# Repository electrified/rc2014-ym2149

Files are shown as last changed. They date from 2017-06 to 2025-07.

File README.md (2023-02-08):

# YM2149F/AY-3-8190 Sound card for the RC2014 computer - Revision 6.1

The `head` of this repository contains the latest version - currently **Rev 6.1**. Please check the version of your board, and select the appropriate tag from the right to get the documentation for your board. e.g [go here for the **Rev 5** (most common) docs](https://github.com/electrified/rc2014-ym2149/tree/4b8af5396633bc87178b81087cec0f71b8307908)

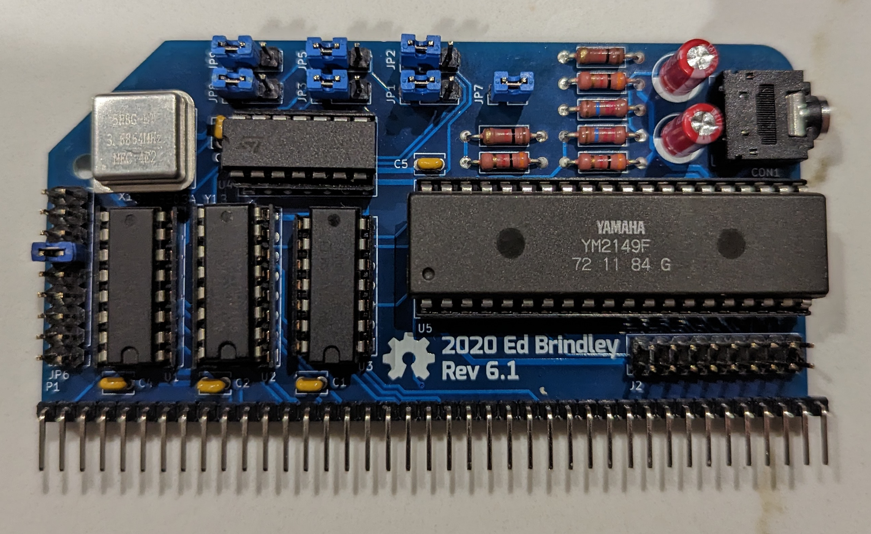
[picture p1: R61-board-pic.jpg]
Picture of the board


Video demonstration: https://www.youtube.com/watch?v=-iLwi9FagFE

## The board
This is a YM2149F/AY-3-8910 sound card for the RC2014 Z80 8-bit computer. It adds the ability to play music on your RC2014!

## What can you use this for?
* Playing music for MSX or ColecoVision Super Game Module compatible software (you may also want a TMS9918A board)
* Playing music ripped from spectrum games
* Playing Spectrum Protracker 2/3 and tunes in MYM format
* Adding music to your own games
* Making music from BASIC or ASM!

## Features

* Stereo Line out, with golden ratio mixer.
* Header for the 2 8-bit I/O ports. These could be used for reading from joysticks, additional serial ports, LED indicators etc.
* Both YM2149F and AY-3-8910 ICs may be used
* Supported in RomWBW
* Possible to jumper to the same IO port as the ZX Spectrum AY
* Known to work on the standard RC2014 setup, as well as on Steve Cousin's SC126 and SC130
* Divides the RC2014 clock by 2 or 4 using flip flops to bring it under the 2Mhz max clock speed of the AY.
* Supports enabling the YM2149F's internal clock divider. This means that bus speeds up to 16Mhz could be supported without overclocking the chip. (AY does not have this feature)
* [George Beckett](https://twitter.com/markgbeckett/) has done some great work getting the board working on the [Minstrel 4th Jupiter Ace compatible computer](https://www.thefuturewas8bit.com/minstrel4th.html). See [his repository here](https://github.com/markgbeckett/jupiter_ace/tree/master/rc2014_sound_card) for information. 

## History
The Yamaha YM2149F and General Instrument AY-3-8910 are popular sound chips that were used in a wide variety of computers and arcade machines in the 1980s and 1990s. The most notable of those being the ZX Spectrum 128, Atari ST and MSX computers.

## Construction Steps

0. If you have bought one of Spencer's kits, obtain a YM2149 chip from your local friendly eBay seller :)
1. Verify the components supplied in the kit match up with [bill of materials](https://github.com/electrified/rc2014-ym2149/blob/master/README.md#bill-of-materials)
2. Solder the components to the board, matching the components in the [BOM](https://github.com/electrified/rc2014-ym2149/blob/master/README.md#bill-of-materials) to the component references printed on the PCB, starting with the lowest height ones first e.g. bypass capacitors and resistors, then moving on to IC sockets, pin headers and do the electrolytic capacitors and output jack last.
3. Insert the ICs in their sockets. The component reference marking on the PCB (e.g. U1) is nearest to pin 1 for all ICs
4. If you have a Z80 based system, configure the jumpers on the board so it looks like the picture in the README. This will ensure it is at the right IO address.
5. Insert board into backplane/SBC
6. Boot into RomWBW ensure you have the "tune.com" application (it's not included in the ROM drive but should be on the disk images)
7. Find some music to play. There are some example files in https://github.com/wwarthen/RomWBW/tree/dev/Source/Apps/Tune/Tunes that you could transfer to the system.
8. Use tune.com to play the music file. If you download the RomWBW*-Package.zip corresponding to whatever version of RomWBW you are using the from the releases page here https://github.com/wwarthen/RomWBW/releases, the tune.com executable will be in the `Binary/Apps` directory.

## Bill Of Materials

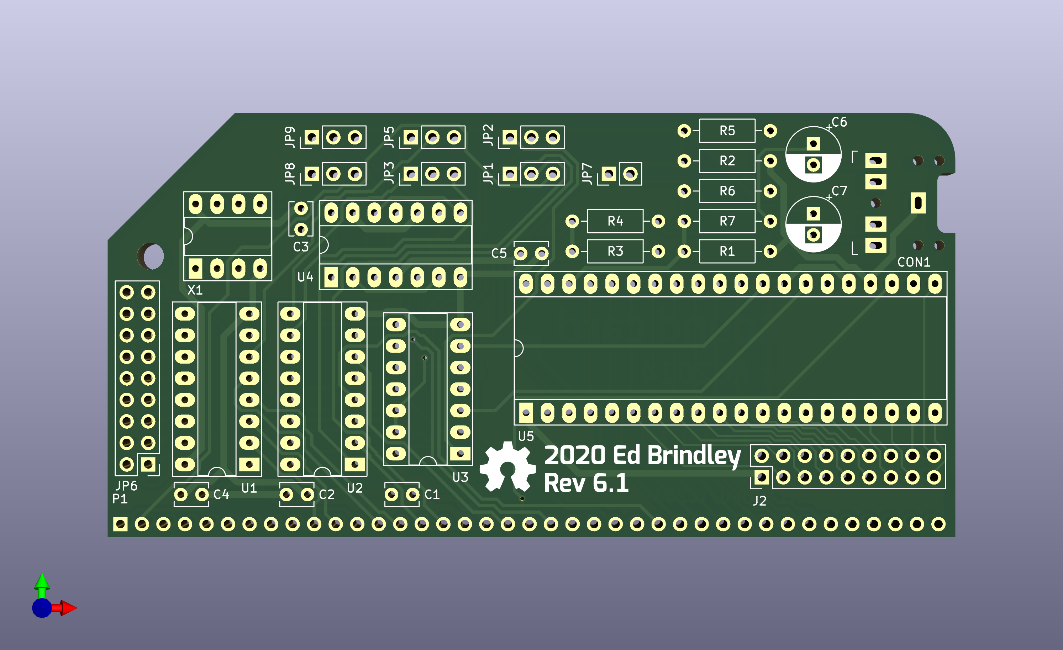
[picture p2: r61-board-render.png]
Picture of the board


Qty|Schematic Reference|Description
---|-------------------|-----------
2|U1 U2| 16 pin DIP socket 2.54 mm pin pitch, 7.62 mm wide
1|U5|	40 pin DIP socket, 2.54mm pin pitch, 15.24mm wide
1|U5|	Yamaha YM2149F or General Instrument AY-3-8910
1|U4|	74HCT74
2|U3 U4| 14 pin DIP socket 2.54 mm pin pitch, 7.62 mm wide
1|U3|	74HCT00
2|U1 U2| 74HCT138
2|R6 R7| 1k6 ohm 1/4 watt metal film resistor
2|R4 R5| 1k ohm 1/4 watt metal film resistor
3|R1 R2 R3|	3k ohm 1/4 watt metal film resistor
1|P1|	40 pin right angled 2.54mm header
1|CON1|	3 or 5 pin 3.5mm PCB mount jack socket (e.g. SJ1-3525N - mouser part 710-860020472001)
2|C6 C7| 4.7uF electrolytic capacitor
5|C1 C2 C3 C4 C5|	0.1uF ceramic capacitor 2.54 mm pin pitch
7|JP1-5 JP8-JP9| 3 x 1 straight pin header 2.54 mm pin pitch
1|JP7| 2 x 1 straight pin header 2.54 mm pin pitch
1|JP6| 9 x 2 straight pin header 2.54 mm pin pitch
1|J2| 9 x 2 straight pin header 2.54 mm pin pitch
1|X1| Half size Oscillator socket (or DIP-8 socket with middle pins removed)
5|Various|Jumpers

The majority of the components are widely available, however both the AY-3-8910 and YM2194F are unfortunately not in production any more, but reclaimed chips are available fairly plentifully on eBay from suppliers in China. I would suggest using a standard 40 pin DIL socket for the AY as they are more accommodating to bent/soldered pins than a turned pin ones.

## Addressing

The board contains a set of jumpers to select the address at which the sound chip will respond to commands.  The jumpers settings are described in detail below.

"Normal" or MSX addressing mode is recommended.

### Normal/MSX/ColecoVision addressing
MSX mode uses standard 8-bit port addressing. This board allows the base address to be any value from 00-F0 (MSX uses A0 and ColecoVision SGM uses 50 for the PSG's base address). Different ports in the lower nybble are used for reading and writing the address and data registers.  Writing to port `X0h` selects the PSG register. Writing to port `X1h` writes the selected PSG register value and reading port `X2h` reads the selected PSG register value.

i.e. for MSX:
Configure base address: A0h
Register write address: A0h
Data write address: A1h
Data read address: A2h

and ColecoVision
Configure base address: 50h
Register write address: 50h
Data write address: 51h
Data read address: 52h

### ZX Spectrum addressing
ZX Spectrum mode uses an uncommon 16-bit I/O addressing scheme for the PSG. This is possible since the Z80 puts the value of the B register on the upper 8 bits of the address bus when performing an `IN r, (C)` or `OUT (C), r` instruction.  Setting `A15` to `1` and `A1` to `0` enables the PSG and `A14` distinguishes between PSG address and data registers. To select a PSG register, set `BC` to `FFFDh` and use `OUT (C), r` to select the address in r. To write a value to the selected PSG register set `BC` to `BFFDh` and use `OUT (C), r` to write the value in r. To read the selected PSG register value, set `BC` to `FFFDh` and use `IN r, (C)`. Note that r must be A, D, E, H, or L since B and C are required for addressing.  Also note that `OUT (n), A` and `IN A, (n)` instructions won't work since they put the value of A on the upper 8 bits of the address bus.

### Compatibility with Rev 5
REV6 no longer supports the `D0/D8` addresses used by default in REV5 and earlier.  REV6 introduced MSX-compatible addressing and supporting addresses used by REV5 and earlier would have required additional chips. This seems like a fair tradeoff since existing software that uses the original default addresses for this board is minimal compared to software that uses the MSX or Spectrum addressing schemes.

Note: Pin 1 on each jumper is identified by having square pad.

### JP1-JP3
Select between MSX and ZX Spectrum decoding. All 3 jumpers should all be set to either MSX or ZX Spectrum mode. For Spectrum mode, JP6 must also be set in position 17-18.  Mixing modes on different jumpers will result in nonsensical address decoding.

pins                 |description
---------------------|--------------
1-2 (Left Position)  | Normal/MSX/ColecoVision
2-3 (Right Position) | ZX Spectrum

### JP5
Selects the upper or lower half of the address range selected by JP6.

pins                 | description
---------------------|------------
1-2 (Left position)  | Upper (odd) half
2-3 (Right position) | Lower (even) half

### JP6
Selects the base address for MSX addressing mode. For Spectrum addressing, the rightmost position (17-18) must be used.  MSX addressing can use any base address from 00-F0, where JP6 selects the 3 most significant bits.  JP5 is used to set `A4`, thus selecting the lower or upper half of the range chosen by JP5.

pins|with JP5 on 1&2
----|------------
1-2 (Bottom most position) | 0x00
3-4 | 0x20
5-6 | 0x40
7-8 | 0x60
9-10 | 0x80
11-12 | 0xA0 (MSX Compatible)
13-14 | 0xC0
15-16 | 0xE0
17-18 (Top most position) | Spectrum Mode

pins|with JP5 on 2&3
----|------------
1-2 (Bottom most position) | 0x10
3-4 | 0x30
5-6 | 0x50 (ColecoVision SGM compatible)
7-8 | 0x70
9-10 | 0x90
11-12 | 0xB0
13-14 | 0xD0
15-16 | 0xF0
17-18 (Top most position) | Spectrum Mode

### JP7

YM2149 only, internally halve clock if jumpered

### JP8

Use bus clock or onboard oscillator

pins|description
----|------------
1-2 | Oscillator
2-3 | Bus clock

### JP9
Clock divisor. Divides the bus or oscillator 

pins|description
----|------------
1-2 | Divide by 2
2-3 | Divide by 4 - Default

## Outputs

CON1 - 3.5mm audio out

J2 - 2 8 bit I/O ports

## How to use from BASIC

See the BASIC programs in ```player/test```. ```descend.bas``` plays some descending tones, ```io_in.bas``` demonstrates reading from the IO port, and ```io_out.bas``` demonstrates writing to an IO port.

## How to use from RomWBW

Wayne has incorporated a player called "Tune" into RomWBW that will play PT2, PT3 and MYM files. See here for the source: https://github.com/wwarthen/RomWBW/tree/master/Source/Apps/Tune. It should be present within RomWBW disk images.

Alternatively start the Microsoft BASIC interpreter mbasic, and refer to the above BASIC examples.

## MSX Configuration

#A0 (write) 	Register write port
#A1 (write) 	Value write port
#A2 (read) 	Value read port

## Sources for music to play

ZXArt is my favourite site: https://zxart.ee/eng/music/mainpage/

http://zxtunes.com/ is another massive collection.

http://ftp.kameli.net/pub/mym/ has a collection of MYM files

This tool compresses YMs to MYMs, which makes a lot of music available: http://osdk.org/index.php?page=documentation&subpage=ym2mym although your mileage may vary, I found some YMs weren't convertible.

This is a large archive of YM tunes to try with the above tool: ftp://ftp.modland.com/pub/modules/YM/

The CPC Power site has a lot of Amstrad YMs: https://www.cpc-power.com/index.php?page=database

There are some PT2s, PT3s and YMs on Sergei Bulba's site: http://bulba.untergrund.net/music_e.htm (although a lot of tunes in other formats)

## Credits
* Some ideas and the golden ratio output mixing were taken from the Melodik 2 design here: http://hw.speccy.cz/melodik2.html
* MSX decoding, many thanks to J.B. Langston

## License

Copyright Ed Brindley 2017-2022.

This source describes Open Hardware and is licensed under the CERN-OHL-P v2
You may redistribute and modify this documentation and make products using it under the terms of the CERN-OHL-P v2 (https:/cern.ch/cern-ohl). This documentation is distributed WITHOUT ANY EXPRESS OR IMPLIED WARRANTY, INCLUDING OF MERCHANTABILITY, SATISFACTORY QUALITY AND FITNESS FOR A PARTICULAR PURPOSE. Please see the CERN-OHL-P v2 for applicable conditions

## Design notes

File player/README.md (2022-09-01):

# Assembling within a Docker container

## Prerequisites
* Docker
* This repo checked out

## Building the docker image
To build the docker container containing the tools, change into this directory in the git checkout then
```
docker build -t z80-build .
```

You should see some output similar to the following (there will be a lot more when built for the first time with no cache)

```
Sending build context to Docker daemon  586.2kB
Step 1/4 : FROM debian:unstable-slim
 ---> 36663c2c334f
Step 2/4 : RUN apt-get -y update && apt-get -y install build-essential git bison flex libxml2-dev subversion zlib1g-dev m4 ragel re2c dos2unix texinfo texi2html gdb curl perl cpanminus ccache libboost-all-dev libmodern-perl-perl libyaml-perl liblocal-lib-perl libcapture-tiny-perl libpath-tiny-perl libtext-table-perl libdata-hexdump-perl libregexp-common-perl libclone-perl libfile-slurp-perl && cpanm --local-lib=~/perl5 App::Prove CPU::Z80::Assembler Data::Dump Data::HexDump File::Path List::Uniq Modern::Perl Object::Tiny::RW Regexp::Common Test::Harness Text::Diff Text::Table YAML::Tiny && eval $(perl -I ~/perl5/lib/perl5/ -Mlocal::lib) && git clone --recurse-submodules --branch v1.20.1 https://github.com/z00m128/sjasmplus.git && git clone --recurse-submodules https://github.com/z88dk/z88dk.git && cd sjasmplus && make && cd ../z88dk && export BUILD_SDCC=1 && export BUILD_SDCC_HTTP=1 && chmod 777 build.sh && ./build.sh
 ---> Using cache
 ---> 2d4bfb98bbca
Step 3/4 : ENV PATH "/z88dk/bin:/sjasmplus:$PATH"     ZCCCFG="/z88dk/lib/config/"
 ---> Using cache
 ---> 472186f6ac08
Step 4/4 : WORKDIR /src
 ---> Using cache
 ---> a4e7ad1df2e2
Successfully built a4e7ad1df2e2
Successfully tagged z80-build:latest
```

## Running the assembler
To assemble PTxPlay with tune and generate an intel hex file, run the following commands

First run this to assemble
```
docker run -v ${PWD}:/src/ -it z80-build sjasmplus PTxPlay.asm
```

You should see output similar to
```
SjASMPlus Z80 Cross-Assembler v1.20.1 (https://github.com/z00m128/sjasmplus)
Pass 1 complete (0 errors)
Pass 2 complete (0 errors)
PTxPlay.asm(292): warning: value 0x1F0 is truncated to 8bit value: 0xF0
PTxPlay.asm(352): warning: value 0xC774 is truncated to 8bit value: 0x74
PTxPlay.asm(399): warning: value 0xC780 is truncated to 8bit value: 0x80
PTxPlay.asm(672): warning: value 0x1A3E5 is truncated to 16bit value: 0xA3E5
PTxPlay.asm(994): warning: value 0xC949 is truncated to 8bit value: 0x49
PTxPlay.asm(1058): warning: value 0xC849 is truncated to 8bit value: 0x49
PTxPlay.asm(1412): warning: value 0xDD8 is truncated to 8bit value: 0xD8
PTxPlay.asm(1424): warning: value 0xCDA is truncated to 8bit value: 0xDA
PTxPlay.asm(1437): warning: value 0xE08 is truncated to 8bit value: 0x08
PTxPlay.asm(1449): warning: value 0xFC0 is truncated to 8bit value: 0xC0
include data: name=tunes/MmcM_-_Recollection_(2015).pt3 (7963 bytes) Offset=0  Len=7963
Pass 3 complete
Errors: 0, warnings: 10, compiled: 1513 lines, work time: 0.004 seconds
```

Then convert the binary file to intel hex with the following
```
docker run -v ${PWD}:/src/ -it z80-build z88dk-appmake +rom -b PTxPlay.out --org 49152 --ihex
```

You should now have a PTxPlay.ihx in the current directory.

## Changing the song being played
Search for `MDLADDR EQU $` in PTxPlay.asm and change the referenced song

## Changing the port
Search for `IF RC` and adjust the output code ports

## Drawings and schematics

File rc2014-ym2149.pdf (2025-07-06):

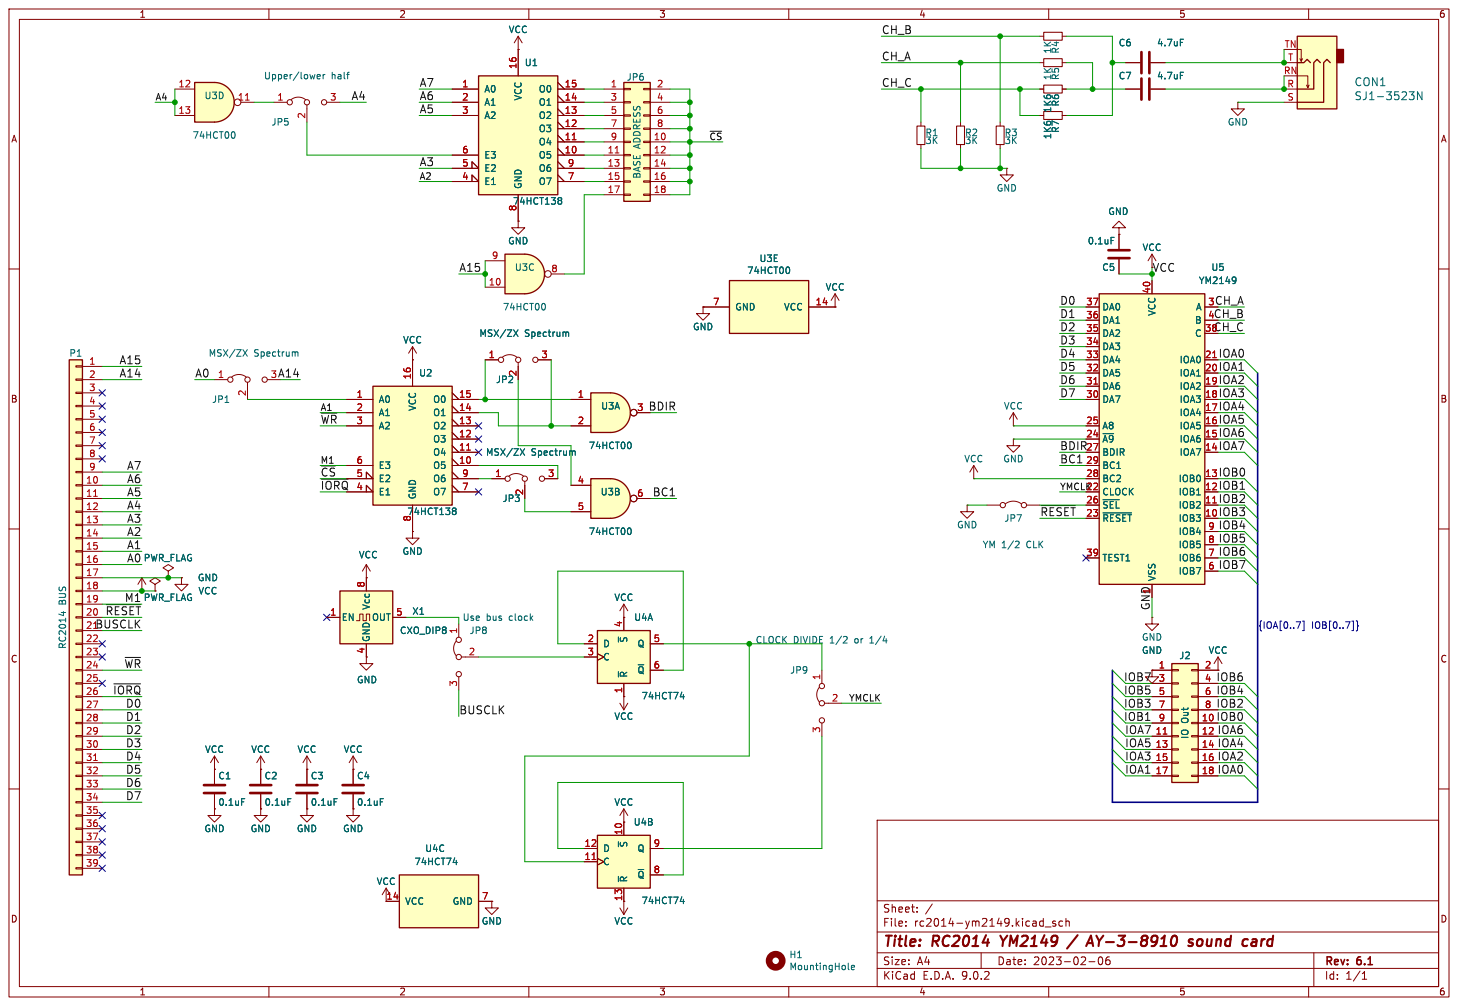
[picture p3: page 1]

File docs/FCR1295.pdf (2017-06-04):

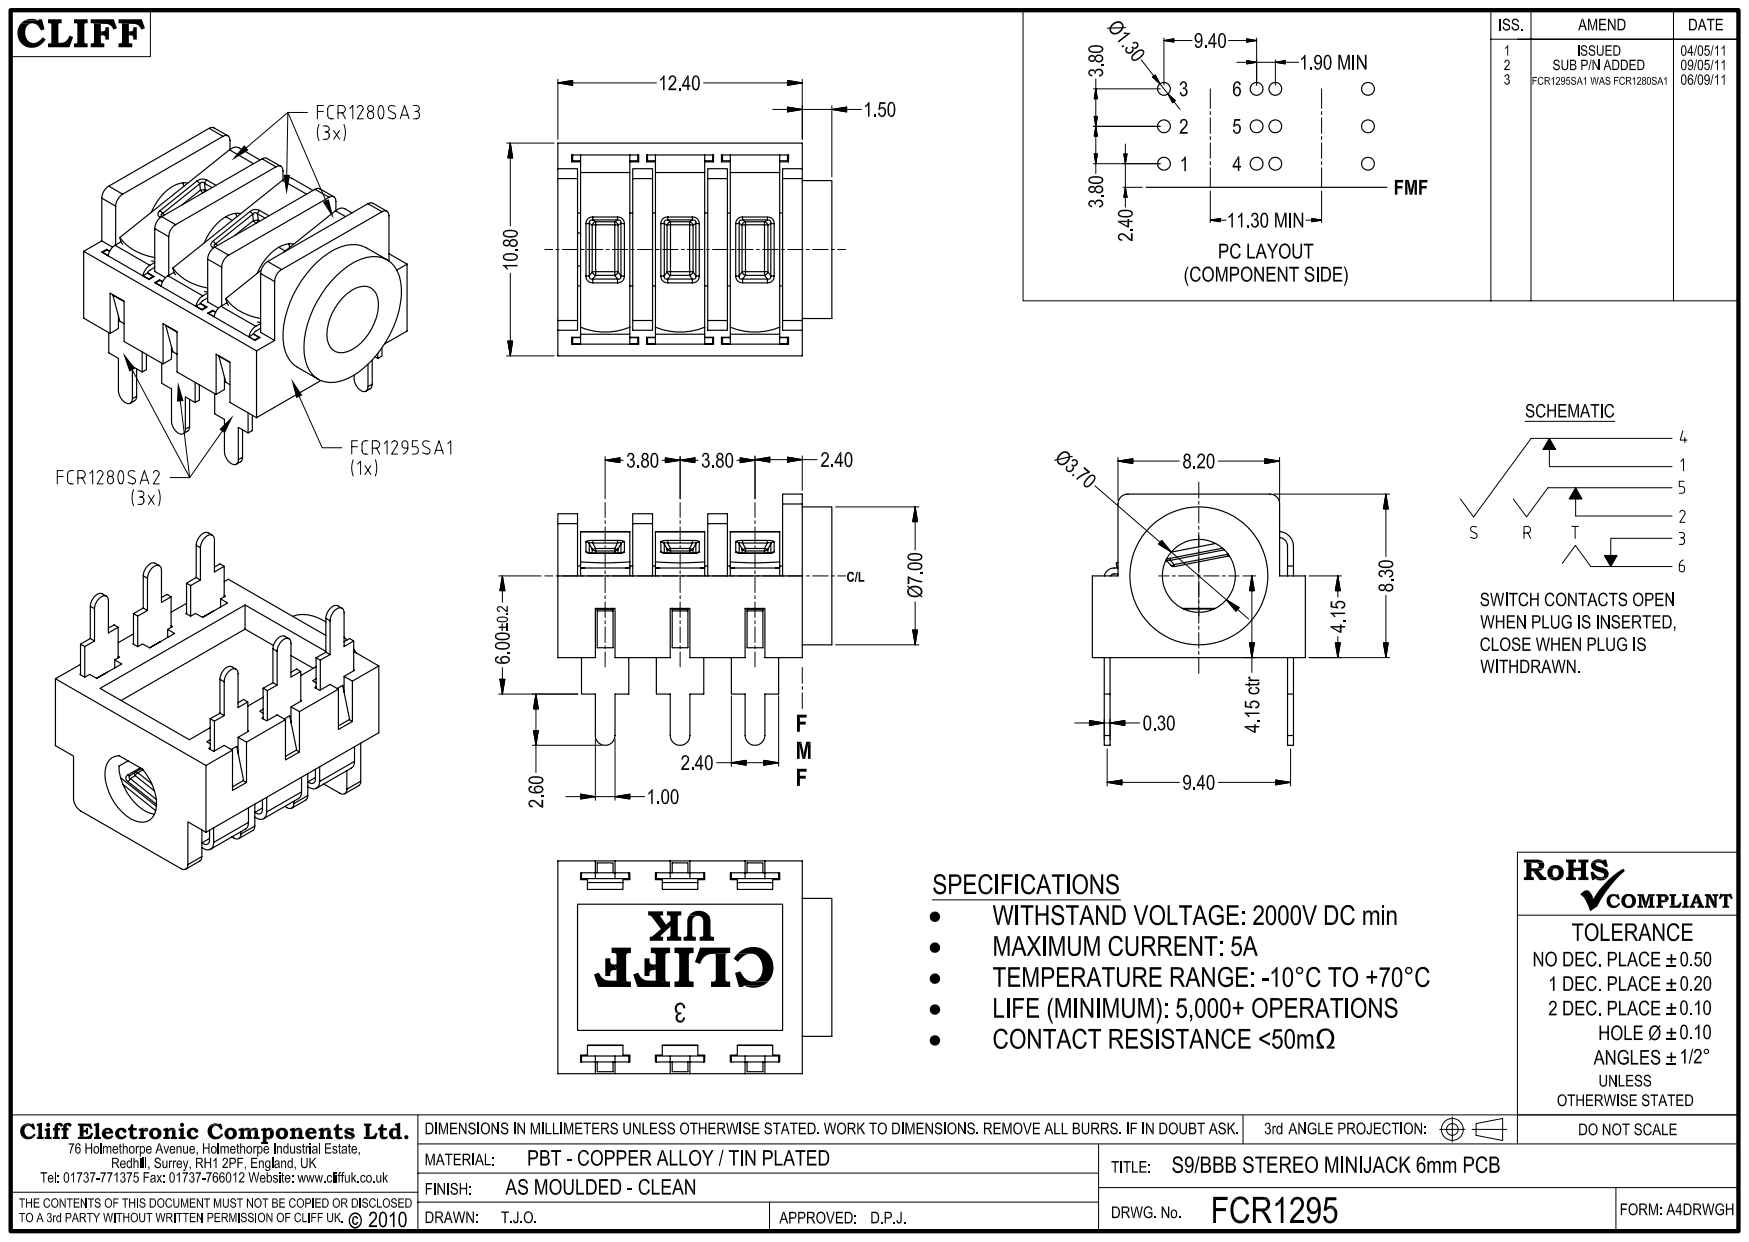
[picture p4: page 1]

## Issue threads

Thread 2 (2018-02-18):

Separate TEST.BAS into 3 separate programs

jblang, 2018-02-18:
After I assembled my card, I wanted to do a quick test to verify that it was alive. I copied TEST.BAS and pasted it into MBASIC, not noticing it's actually 3 separate programs. The line numbers are the only clue that this is the case, and I wasn't paying close attention so I missed it. This made me question whether my sound card was working right because the program didn't do what it was supposed to, and I spent a lot of time scratching my head. Separating the programs into individual files would prevent someone else from making this mistake.

electrified, 2018-02-18:
Thanks, have split the file and updated the readme.

jblang, 2018-02-22:
Just noticed you have GPIO out and input examples backwards in the files you split out (i.e., the program does the opposite of what the filename indicates).

electrified, 2018-02-22:
Whoops! Thanks, I've fixed.

Closed 2018-02-18.

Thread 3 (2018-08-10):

C6 C7 capacitor values

b1ackmai1er, 2018-08-10:
Hi  The original melodik schematic shows 4.7uF caps on the audio output but your RC2014 circuit uses 470uF. Is this change intentional? It appears to be a very high value compared to other circuits which vary from 1uF to 10uF. Regards Phil

electrified, 2018-08-10:
Hi there,
No this was not intentional - I think it's a mistake! The main purpose of the capacitors is to block the DC offset which is present on the YM2149s output pins.

Thanks for pointing this out, when I find time I'll try some lower values and see what the effect is.

tgmaxx, 2020-09-15:
Capacitor C6 and C7 in the Octopart BOM are 16V rating. Those have a diameter of 8mm which is too much for side-by-side mounting in the board. The lead spacing is also not correct for the board (should be 2.5mm). It appears the 6.3V caps are the correct ones with part number ECA0JHG471.

I know you mentioned sourcing the Audio jack, but it appears to be unique to Cliff, so there are no alternatives. In the USA, buying the jack from Newark is $0.65 plus a flat rate shipping charge of $9.99, making it the highest cost item on the board (unless other items can be included on the same order).

electrified, 2023-02-06:
This has now been fixed in the latest schematics.

Closed 2023-02-06.

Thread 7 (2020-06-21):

Use more widely available 3.5mm jack socket

electrified, 2020-06-21:

electrified, 2020-11-25:
Fixed in R6

Closed 2020-11-25.

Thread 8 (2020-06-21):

Add on board oscillator/ ability to divide clock down by more than 2

electrified, 2020-06-21:
See https://groups.google.com/forum/#!topic/rc2014-z80/Z36yUhXvdBY

Suggestions from that thread:

Add oscillator

The other way around this is to replace on the sound-card the 74HCT74 (dual D type FF) with a 74HCT175 (quad), so we can divide the CLK by 8 or even 16 and meet the chip requirements without slowing down the CPU. Maybe this wider clock-divider front-end should be adopted for future designs with faster CPU clock frequencies in mind. It's not uncommon to see new builders use the 20 MHz CMOS version of the Z80.

electrified, 2020-11-25:
Fixed in R6

Closed 2020-11-25.

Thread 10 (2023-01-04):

Rev 6.1 jumpers

GrantMeStrength, 2023-01-04:
Hi! Any information on the rev 6.1 jumpers? Thank you! -john

electrified, 2023-01-09:
Hi John,

The text in the main readme should be accurate - https://github.com/electrified/rc2014-ym2149 but the images are for the v6 version.

The jumpers on V6 and V6.1 have the same function number for number but their positioning has moved, V6 had a JP4 which is no longer present on V6.1.

I will try and update the images in the readme soon, but I don't currently have a v6.1 board to hand to photograph.

Pax-nl, 2024-06-22:
Does this help?, I can make a better one tomorrow with daylight.

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

I would like to know the correct settings to play the pt3 files with the player in CP/M, the jumper settings on this photo do not seem to work, but this is the first time a tried as I have the card soldered today :D

electrified, 2024-06-24:
Hi @Pax-nl, what version of RomWBW are you using and where did you get it (i.e. was it supplied on a pre-flashed ROM in a kit by Spencer or did you compile it yourself?)

Hopefully we can get to the bottom of why you can't get it to work!

Thanks,
Ed

electrified, 2024-06-24:
I've just noticed you have JP8 on 1-2, it needs to be on 2-3 when the oscillator is omitted (see https://github.com/electrified/rc2014-ym2149?tab=readme-ov-file#jp8), that would definitely prevent it from working.

Pax-nl, 2024-06-24:
Yes this was the issue and therefore the solution.

Thank you!

electrified, 2024-06-24:
Awesome, glad you got it working.

Pax-nl, 2024-06-25:
@electrified

If I compile [PTxPlay.asm](https://github.com/electrified/rc2014-ym2149/blob/main/player/PTxPlay.asm) can this be run from CP/M 2.2 or can it only be run from RomWBW, if CP/M is possible what would be the jumper settings for REV 6.1 board? (all jumpers)

I tried several settings but nothing gets even a beep.

electrified, 2024-06-25:
Use the ptxplay from feilipu's repo as you are currently doing - ensuring you have `DEFC REV5	= 0` set. The version in this repo is really only for if you don't have CP/M at all (it builds the code and music into one image)

The board jumpers should look like the below picture if you don't have an oscillator. Looking at your pic you also have JP6 and JP5 jumpered wrong (apologies I didn't spot this earlier). JP6 wants to be on the 4th set of pins down and JP5 on 1-2. This will set the address ports to A0 and A1, the MSX ports.

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

As well as ptxplay you can try decend.bas in mbasic https://github.com/electrified/rc2014-ym2149/blob/main/player/test/descend.bas

Pax-nl, 2024-06-27:
Thank you for your detailed explanation.

I was hoping to get the card in D8/D0 mode so I could use your PT3 library.

electrified, 2024-06-28:
D8/D0 addressing isn't possible with Rev6.1 (see https://github.com/electrified/rc2014-ym2149?tab=readme-ov-file#compatibility-with-rev-5)

The library should work with A0/A1 if you set RC=0 and MSX=1 https://github.com/electrified/rc2014-ym2149/blob/main/player/PTxPlay.asm#L11

Pax-nl, 2024-06-28:
Yes, I got that from your detailed explanation, thank you for all your help, I can continue enjoying your Sound Module, very good job, I love it..

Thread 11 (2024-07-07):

BOM issues

zomgugoff, 2024-07-07:
The BOM does not include a part number for the oscillator and has the incorrect Mouser part# listed for the 3.5mm jack.  SJ1-3525N is Mouser part# 490-SJ1-3525N. The one listed is for a capacitor.

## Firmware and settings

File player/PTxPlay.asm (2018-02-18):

;Universal PT2 and PT3 player for ZX Spectrum and MSX
;(c)2004-2007 S.V.Bulba <vorobey@mail.khstu.ru>
;http://bulba.untergrund.net (http://bulba.at.kz)

;Release number
Release EQU "1"

;Conditional assembly
;1) Version of ROUT (ZX or MSX standards)
ZX=0
MSX=0
RC=1
;2) Current position counter at (START+11)
CurPosCounter=0
;3) Allow channels allocation bits at (START+10)
ACBBAC=0
;4) Allow loop checking and disabling
LoopChecker=0
;5) Insert official identificator
Id=1

;Features
;--------
;-Can be compiled at any address (i.e. no need rounding ORG
; address).
;-Variables (VARS) can be located at any address (not only after
;code block).
;-INIT subprogram checks PT3-module version and rightly
; generates both note and volume tables outside of code block
; (in VARS).
;-Two portamento (spc. command 3xxx) algorithms (depending of
; PT3 module version).
;-New 1.XX and 2.XX special command behaviour (only for PT v3.7
; and higher).
;-Any Tempo value are accepted (including Tempo=1 and Tempo=2).
;-Fully compatible with Ay_Emul PT3 and PT2 players codes.
;-See also notes at the end of this source code.

;Limitations
;-----------
;-Can run in RAM only (self-modified code is used).
;-PT2 position list must be end by #FF marker only.

;Warning!!! PLAY subprogram can crash if no module are loaded
;into RAM or INIT subprogram was not called before.

;Call MUTE or INIT one more time to mute sound after stopping
;playing

	ORG #C000
	;ORG #100
	; ld hl, startupstr
  ; call print
;Test codes (commented)
	;LD A,2 ;PT2,ABC,Looped
	LD A, 0
	LD (START+10),A
	CALL START
	; ld hl, startupstr
	; call print
;	EI
;_LP	HALT
_LP	CALL START+5
	call pause

	; XOR A
	; IN A,(#FE)
	; CPL
	; AND 15
	JR _LP
	ld hl, endstr
	call print
	JR START+8

TonA	EQU 0
TonB	EQU 2
TonC	EQU 4
Noise	EQU 6
Mixer	EQU 7
AmplA	EQU 8
AmplB	EQU 9
AmplC	EQU 10
Env	EQU 11
EnvTp	EQU 13

;Entry and other points
;START initialize playing of module at MDLADDR
;START+3 initialization with module address in HL
;START+5 play one quark
;START+8 mute
;START+10 setup and status flags
;START+11 current position value (byte) (optional)

START
	LD HL,MDLADDR
	JR INIT
	JP PLAY
	JR MUTE
SETUP	DB 0 ;set bit0, if you want to play without looping
	     ;(optional);
	     ;set bit1 for PT2 and reset for PT3 before
	     ;calling INIT;
	     ;bits2-3: %00-ABC, %01 ACB, %10 BAC (optional);
	     ;bits4-6 are not used
	     ;bit7 is set each time, when loop point is passed
	     ;(optional)
	IF CurPosCounter
CurPos	DB 0 ;for visualization only (i.e. no need for playing)
	ENDIF

;Identifier
	IF Id
	DB "=Uni PT2 and PT3 Player r.",Release,"="
	ENDIF

	IF LoopChecker
CHECKLP	LD HL,SETUP
	SET 7,(HL)
	BIT 0,(HL)
	RET Z
	POP HL
	LD HL,DelyCnt
	INC (HL)
	LD HL,ChanA+CHP.NtSkCn
	INC (HL)
	ENDIF

MUTE	XOR A
	LD H,A
	LD L,A
	LD (AYREGS+AmplA),A
	LD (AYREGS+AmplB),HL
	JP ROUT

INIT
;HL - AddressOfModule
	LD A,(START+10)
	AND 2
	JR NZ,INITPT2

	CALL SETMDAD
	PUSH HL
	LD DE,100
	ADD HL,DE
	LD A,(HL)
	LD (Delay),A
	PUSH HL
	POP IX
	ADD HL,DE
	LD (CrPsPtr),HL
	LD E,(IX+102-100)
	INC HL

	IF CurPosCounter
	LD A,L
	LD (PosSub+1),A
	ENDIF

	ADD HL,DE
	LD (LPosPtr),HL
	POP DE
	LD L,(IX+103-100)
	LD H,(IX+104-100)
	ADD HL,DE
	LD (PatsPtr),HL
	LD HL,169
	ADD HL,DE
	LD (OrnPtrs),HL
	LD HL,105
	ADD HL,DE
	LD (SamPtrs),HL
	LD A,(IX+13-100) ;EXTRACT VERSION NUMBER
	SUB #30
	JR C,L20
	CP 10
	JR C,L21
L20	LD A,6
L21	LD (Version),A
	PUSH AF ;VolTable version
	CP 4
	LD A,(IX+99-100) ;TONE TABLE NUMBER
	RLA
	AND 7
	PUSH AF ;NoteTable number
	LD HL,(e_-SamCnv-2)*256+#18
	LD (SamCnv),HL
	LD A,#BA
	LD (OrnCP),A
	LD (SamCP),A
	LD A,#7B
	LD (OrnLD),A
	LD (SamLD),A
	LD A,#87
	LD (SamClc2),A
	LD BC,PT3PD
	LD HL,0
	LD DE,PT3EMPTYORN
	JR INITCOMMON

INITPT2	LD A,(HL)
	LD (Delay),A
	PUSH HL
	PUSH HL
	PUSH HL
	INC HL
	INC HL
	LD A,(HL)
	INC HL
	LD (SamPtrs),HL
	LD E,(HL)
	INC HL
	LD D,(HL)
	POP HL
	AND A
	SBC HL,DE
	CALL SETMDAD
	POP HL
	LD DE,67
	ADD HL,DE
	LD (OrnPtrs),HL
	LD E,32
	ADD HL,DE
	LD C,(HL)
	INC HL
	LD B,(HL)
	LD E,30
	ADD HL,DE
	LD (CrPsPtr),HL
	LD E,A
	INC HL

	IF CurPosCounter
	LD A,L
	LD (PosSub+1),A
	ENDIF

	ADD HL,DE
	LD (LPosPtr),HL
	POP HL
	ADD HL,BC
	LD (PatsPtr),HL
	LD A,5
	LD (Version),A
	PUSH AF
	LD A,2
	PUSH AF
	LD HL,#51CB
	LD (SamCnv),HL
	LD A,#BB
	LD (OrnCP),A
	LD (SamCP),A
	LD A,#7A
	LD (OrnLD),A
	LD (SamLD),A
	LD A,#80
	LD (SamClc2),A
	LD BC,PT2PD
	LD HL,#8687
	LD DE,PT2EMPTYORN

INITCOMMON

	LD (PTDECOD+1),BC
	LD (PsCalc),HL
	PUSH DE

;note table data depacker
;(c) Ivan Roshin
	LD DE,T_PACK
	LD BC,T1_+(2*49)-1
TP_0	LD A,(DE)
	INC DE
	CP 15*2
	JR NC,TP_1
	LD H,A
	LD A,(DE)
	LD L,A
	INC DE
	JR TP_2
TP_1	PUSH DE
	LD D,0
	LD E,A
	ADD HL,DE
	ADD HL,DE
	POP DE
TP_2	LD A,H
	LD (BC),A
	DEC BC
	LD A,L
	LD (BC),A
	DEC BC
	SUB #F8*2
	JR NZ,TP_0

	IF LoopChecker
	LD HL,SETUP
	RES 7,(HL)

	IF CurPosCounter
	INC HL
	LD (HL),A
	ENDIF

	ELSE

	IF CurPosCounter
	LD (CurPos),A
	ENDIF

	ENDIF

	LD HL,VARS
	LD (HL),A
	LD DE,VARS+1
	LD BC,VAR0END-VARS-1
	LDIR
	LD (AdInPtA),HL ;ptr to zero
	INC A
	LD (DelyCnt),A
	LD HL,#F001 ;H - CHP.Volume, L - CHP.NtSkCn
	LD (ChanA+CHP.NtSkCn),HL
	LD (ChanB+CHP.NtSkCn),HL
	LD (ChanC+CHP.NtSkCn),HL
	POP HL
	LD (ChanA+CHP.OrnPtr),HL
	LD (ChanB+CHP.OrnPtr),HL
	LD (ChanC+CHP.OrnPtr),HL

	POP AF

;NoteTableCreator (c) Ivan Roshin
;A - NoteTableNumber*2+VersionForNoteTable
;(xx1b - 3.xx..3.4r, xx0b - 3.4x..3.6x..VTII1.0)

	LD HL,NT_DATA
	PUSH DE
	LD D,B
	ADD A,A
	LD E,A
	ADD HL,DE
	LD E,(HL)
	INC HL
	SRL E
	SBC A,A
	AND #A7 ;#00 (NOP) or #A7 (AND A)
	LD (L3),A
	EX DE,HL
	POP BC ;BC=T1_
	ADD HL,BC

	LD A,(DE)
	ADD A,T_
	LD C,A
	ADC A,T_/256
	SUB C
	LD B,A
	PUSH BC
	LD DE,NT_
	PUSH DE

	LD B,12
L1	PUSH BC
	LD C,(HL)
	INC HL
	PUSH HL
	LD B,(HL)

	PUSH DE
	EX DE,HL
	LD DE,23
	LD IXH,8

L2	SRL B
	RR C
L3	DB #19	;AND A or NOP
	LD A,C
	ADC A,D	;=ADC 0
	LD (HL),A
	INC HL
	LD A,B
	ADC A,D
	LD (HL),A
	ADD HL,DE
	DEC IXH
	JR NZ,L2

	POP DE
	INC DE
	INC DE
	POP HL
	INC HL
	POP BC
	DJNZ L1

	POP HL
	POP DE

	LD A,E
	CP TCOLD_1
	JR NZ,CORR_1
	LD A,#FD
	LD (NT_+#2E),A

CORR_1	LD A,(DE)
	AND A
	JR Z,TC_EXIT
	RRA
	PUSH AF
	ADD A,A
	LD C,A
	ADD HL,BC
	POP AF
	JR NC,CORR_2
	DEC (HL)
	DEC (HL)
CORR_2	INC (HL)
	AND A
	SBC HL,BC
	INC DE
	JR CORR_1

TC_EXIT

	POP AF

;VolTableCreator (c) Ivan Roshin
;A - VersionForVolumeTable (0..4 - 3.xx..3.4x;
			   ;5.. - 2.x,3.5x..3.6x..VTII1.0)

	CP 5
	LD HL,#11
	LD D,H
	LD E,H
	LD A,#17
	JR NC,M1
	DEC L
	LD E,L
	XOR A
M1      LD (M2),A

	LD IX,VT_+16

	LD C,#F
INITV2  PUSH HL

	ADD HL,DE
	EX DE,HL
	SBC HL,HL

	LD B,#10
INITV1  LD A,L
M2      DB #7D
	LD A,H
	ADC A,0
	LD (IX),A
	INC IX
	ADD HL,DE
	DJNZ INITV1

	POP HL
	LD A,E
	CP #77
	JR NZ,M3
	INC E
M3      DEC C
	JR NZ,INITV2

	JP ROUT

SETMDAD	LD (MODADDR),HL
	LD (MDADDR1),HL
	LD (MDADDR2),HL
	RET

PTDECOD JP #C3C3

;PT2 pattern decoder
PD2_SAM	CALL SETSAM
	JR PD2_LOOP

PD2_EOff LD (IX-12+CHP.Env_En),A
	JR PD2_LOOP

PD2_ENV	LD (IX-12+CHP.Env_En),16
	LD (AYREGS+EnvTp),A
	LD A,(BC)
	INC BC
	LD L,A
	LD A,(BC)
	INC BC
	LD H,A
	LD (EnvBase),HL
	JR PD2_LOOP
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

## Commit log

2017-02-25 updated schematic
    [rc2014-ym2149.sch]
2017-02-26 experiment with playing yms
    [rc2014-ym2149.sch]
2017-03-12 start laying out pcb
    [rc2014-ym2149.kicad_pcb, rc2014-ym2149.sch]
2017-03-14 make pcb more rc2014 like
    [rc2014-ym2149.kicad_pcb, rc2014-ym2149.sch]
2017-03-18 more work on pcb
    [rc2014-ym2149.kicad_pcb, rc2014-ym2149.sch]
2017-03-19 1st attempt at pcb layout complete
    [rc2014-ym2149.kicad_pcb, rc2014-ym2149.sch]
2017-03-19 PCB relayout
    [rc2014-ym2149.kicad_pcb, rc2014-ym2149.sch]
2017-03-20 Update pcb again
    [rc2014-ym2149.kicad_pcb, rc2014-ym2149.sch]
2017-03-28 Messing about with address decoding
    [rc2014-ym2149.kicad_pcb, rc2014-ym2149.sch]
2017-04-02 Fix all ERC errors
    [rc2014-ym2149.sch]
2017-04-02 Add ground fill and create gerbers
    [rc2014-ym2149-B.Cu.gbr, rc2014-ym2149-B.Mask.gbr, rc2014-ym2149-B.SilkS.gbr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]
2017-04-17 Update readme, remove non project stuff
    [rc2014-ym2149.sch]
2017-04-29 Use NAND to invert output from first 74HCT138
    [rc2014-ym2149-B.Cu.gbr, rc2014-ym2149-B.Mask.gbr, rc2014-ym2149-B.SilkS.gbr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]
2017-05-03 Playing aorund with interrupts
2017-05-12 More test programs and changes for Rev 3 PCB
    [rc2014-ym2149.kicad_pcb, rc2014-ym2149.sch]
2017-05-13 Finish changes for rev3
    [rc2014-ym2149-Edge.Cuts.gbr, rc2014-ym2149-F.Cu.gbr, rc2014-ym2149.gbl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]
2017-05-24 Update docs, as manufactured for R3 board
2017-06-04 Get interrupts working
2017-06-05 Update BOM table formatting
2017-06-08 Update pulldown values to 3k
    [rc2014-ym2149.sch]
2017-07-10 Rev 5
    [rc2014-ym2149.kicad_pcb, rc2014-ym2149.sch]
2017-07-10 Rev 5 - further work
    [rc2014-ym2149.kicad_pcb]
2017-07-16 Rev 5 as sent to be manufactured
    [rc2014-ym2149.kicad_pcb, rc2014-ym2149.sch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]
2020-04-21 WIP updating schematic
    [rc2014-ym2149.sch]
2020-06-19 Work in progress converting to Kicad 5
    [rc2014-ym2149.kicad_pcb, rc2014-ym2149.sch]
2020-06-21 Update for Kicad 5 complete
    [rc2014-ym2149.kicad_pcb, rc2014-ym2149.sch]
2020-06-22 Initial rev 6
    [rc2014-ym2149.kicad_pcb, rc2014-ym2149.sch]
2020-06-24 Rev 6 as sent to JLCPCB
    [rc2014-ym2149-B_Cu.gbr, rc2014-ym2149-B_Mask.gbr, rc2014-ym2149-B_SilkS.gbr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]
2020-06-29 Add hole
    [rc2014-ym2149.kicad_pcb]
2020-07-01 Update docs for R6
    [rc2014-ym2149-B_Cu.gbr, rc2014-ym2149-B_Mask.gbr, rc2014-ym2149-B_SilkS.gbr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]
2020-07-19 Remove unneccessary jumper
    [rc2014-ym2149.kicad_pcb, rc2014-ym2149.sch]
2020-07-22 Finalise R6.1, generate gerbers etc
    [rc2014-ym2149-B_Cu.gbr, rc2014-ym2149-B_Mask.gbr, rc2014-ym2149-B_SilkS.gbr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]
2022-02-28 Partial upgrade for kicad 6
    [rc2014-ym2149.kicad_pcb, rc2014-ym2149.kicad_sch]
2022-03-07 remove extraneous files
    [rc2014-ym2149.kicad_sch, rc2014-ym2149.sch]
2022-03-08 further tidyup in prep for a 6.2
    [rc2014-ym2149.kicad_pcb, rc2014-ym2149.kicad_sch]
2023-01-09 Update board render to R6.1, opened in latest version of Kicad and update as needed
    [rc2014-ym2149.kicad_pcb, rc2014-ym2149.kicad_sch]
2023-01-09 Update render, move X1 ref silkscreen back to original R6.1 location, regenerate gerbers
    [rc2014-ym2149-B_Cu.gbr, rc2014-ym2149-B_Mask.gbr, rc2014-ym2149-B_SilkS.gbr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]
2023-01-09 Change U5 footprint back to socket as per original R6.1
    [rc2014-ym2149-B_Cu.gbr, rc2014-ym2149-B_Mask.gbr, rc2014-ym2149-B_Silkscreen.gbr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]
2023-01-09 Use JLCPCB recommended settings and regenerate gerbers
    [rc2014-ym2149-B_Cu.gbr, rc2014-ym2149-B_Mask.gbr, rc2014-ym2149-B_Silkscreen.gbr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]
2023-01-26 Experiment with iBom
    [rc2014-ym2149.kicad_pcb, rc2014-ym2149.kicad_sch]
2023-02-06 update output capacitor values
    [rc2014-ym2149.kicad_pcb, rc2014-ym2149.kicad_sch]
2023-02-08 Update board image
2023-03-06 Upgrade to Kicad 7
    [rc2014-ym2149.kicad_pcb, rc2014-ym2149.kicad_sch]
2023-03-06 update moved library connector
    [rc2014-ym2149.kicad_sch]
2024-06-28 update for kicad 8
    [rc2014-ym2149.kicad_pcb, rc2014-ym2149.kicad_sch]
2025-03-01 update project for kicad 9
    [rc2014-ym2149.kicad_pcb, rc2014-ym2149.kicad_sch]
2025-05-13 update symbols to those in kicad 9 library
    [rc2014-ym2149.kicad_pcb, rc2014-ym2149.kicad_sch]
2025-07-06 fix footprint mappings
    [rc2014-ym2149.kicad_pcb, rc2014-ym2149.kicad_sch]
2025-07-06 add PDF of schematic
2026-05-15 migrate to kicad 10
    [rc2014-ym2149.kicad_pcb, rc2014-ym2149.kicad_sch]
2026-05-16 fix component mapping
    [rc2014-ym2149.kicad_pcb, rc2014-ym2149.kicad_sch]
2026-05-18 update datasheet refs
    [rc2014-ym2149.kicad_sch]
2026-06-25 add kibot drc filters
